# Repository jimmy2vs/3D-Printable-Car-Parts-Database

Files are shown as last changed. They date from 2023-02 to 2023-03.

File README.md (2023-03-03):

# 3D-Printable-Car-Parts-Database

I drive a 1995 BMW M3.  It is an amazing car and brings me so much joy to drive.  It's also slowly disintigrating.  30 year old plastic and glue were not made to last.  

This project started as a way to keep my 90's cars on the road and looking nice.  Tinkering around with this stuff is the thing I can't not do.  Maybe you're the same way.  This is a collection of 3d-printable parts, upholstery patterns, and related repair materials for all sorts of cars from this era.  Take what you find here and apply it to make something for your own car.  Share what you learn with your own enthusiast community.

We've entered an era where we don't fix things anymore.  So many things today aren't repairable or are engineered to have a finite life span.  Cars are no different.  There are so many great sports cars the 80's, 90's and early 2000's.  Icons that are still affordable and loads of fun to drive today.  This project is dedicated to the art and craftsmanship of keeping these cars on the road for many more years to come.

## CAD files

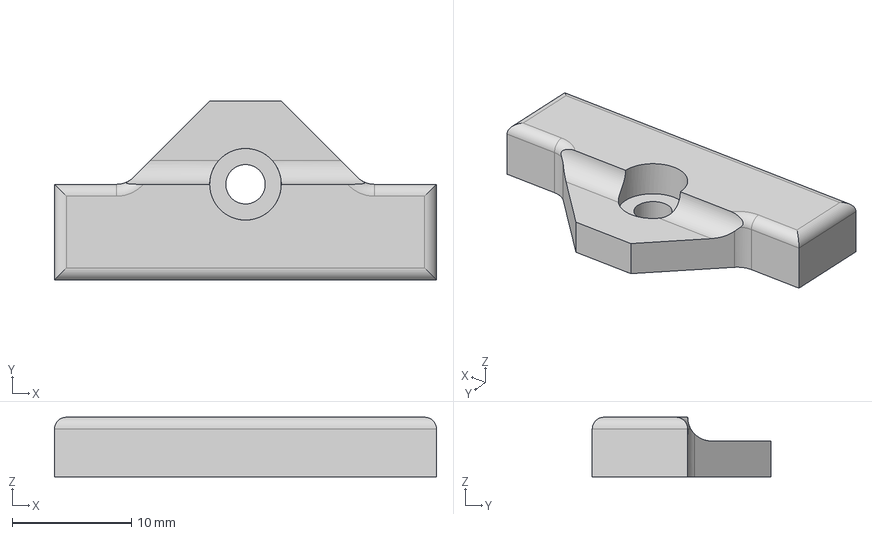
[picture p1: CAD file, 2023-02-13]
BMW/3-series/e36 (1992-1999)/M-tech bumper mesh repair tabs/e36 Front Bumper Mesh Hold Down v2.step
32.0 x 15.0 x 5.00 mm

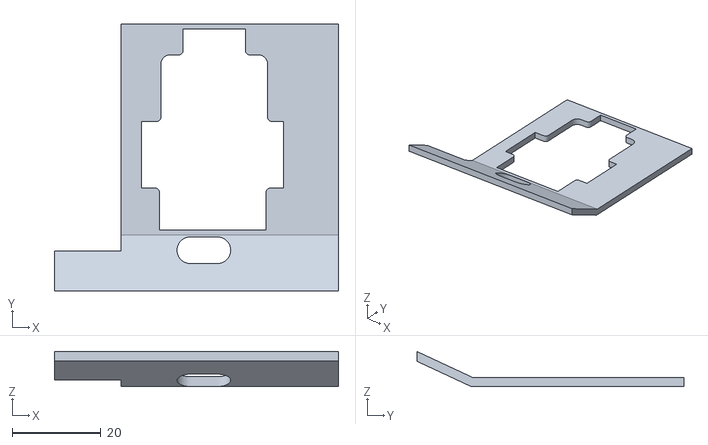
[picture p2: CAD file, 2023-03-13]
Chevrolet/Corvette/C5 (1997-2004)/c5 Knee bolster repair tab RIGHT v11.stl
64.0 x 60.2 x 7.92

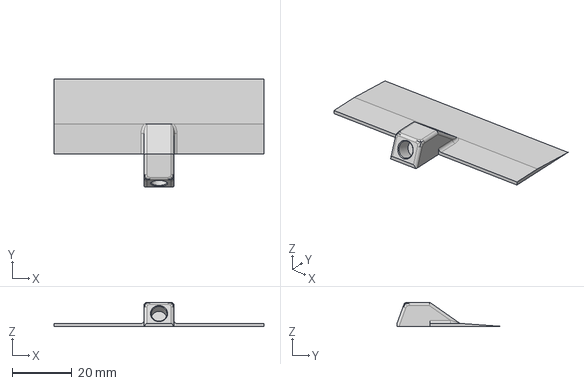
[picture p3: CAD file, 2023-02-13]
BMW/3-series/e36 (1992-1999)/M-tech bumper mesh repair tabs/e36 Front bumper mesh lower mount v10.step
70.0 x 36.0 x 8.08 mm

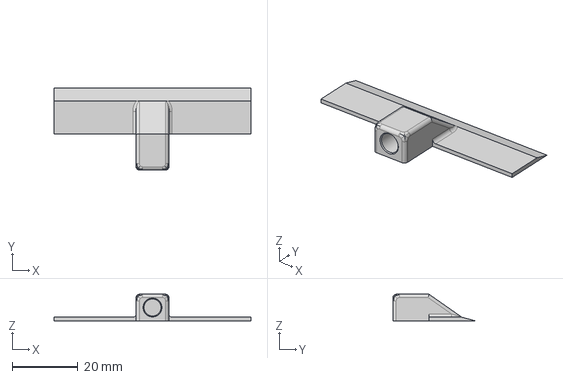
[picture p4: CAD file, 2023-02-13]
BMW/3-series/e36 (1992-1999)/M-tech bumper mesh repair tabs/e36 Front bumper mesh upper mount v10.step
60.0 x 25.0 x 8.08 mm

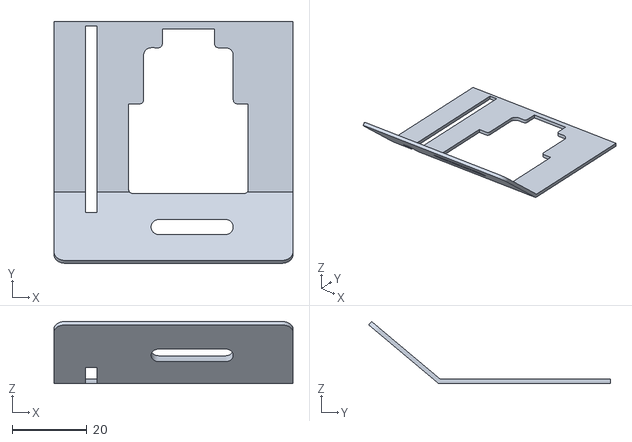
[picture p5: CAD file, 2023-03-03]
Chevrolet/Corvette/C5 (1997-2004)/Knee bolster repair tab v5.stl
64.0 x 64.7 x 16.6

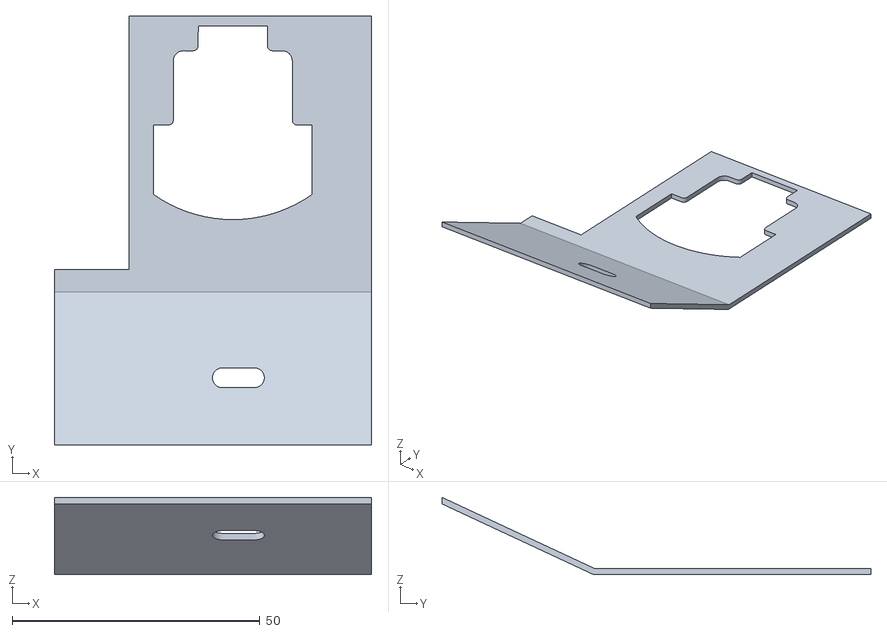
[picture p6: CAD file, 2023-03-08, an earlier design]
Chevrolet/Corvette/C5 (1997-2004)/c5 Knee bolster repair tab RIGHT v6.stl
64.0 x 86.5 x 15.6

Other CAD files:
BMW/3-series/e36 (1992-1999)/M-tech bumper mesh repair tabs/e36 Front Bumper Mesh Hold Down mk2 v2.stl
BMW/3-series/e36 (1992-1999)/M-tech bumper mesh repair tabs/e36 Front bumper mesh lower mount v10.stl
BMW/3-series/e36 (1992-1999)/M-tech bumper mesh repair tabs/e36 Front bumper mesh upper mount v10.stl

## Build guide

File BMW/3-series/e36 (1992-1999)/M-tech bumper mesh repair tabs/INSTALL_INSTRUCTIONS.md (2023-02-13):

# Why make this?
On the 1992-1999 BMW e36 3-series cars with the M-TECH front bumper the lower grill mesh is attached to the bumper cover by a series of plastic posts molded into the grill opening and secured by one-way push clips.  Over time these plastic posts fatigue and break off.  The posts are not individually placeable.  The only remedy is to purchase, paint, and install new bumper cover.  This repair kit replaces the plastic posts and one way-nuts with a bonded in theaded insert and screw-in clamp which is far sturdier and makes the lower grill mesh easily relacable in the event of future damage.

## Print these parts
- e36 Front Bumper Mesh Hold Down (print 5 of these)
- e36 Front bumper mesh lower mount (print 2 of these)
- e36 Front bumper mesh upper mount (print 3 of these)

As for filiament type, PETG or ABS/ASA are preferred.  PLA will work, but may not have long term durability.

## You also need these parts
Available from McMaster-Carr, Amazon, AliExpress, some local hardware stores.
- M3x5mm heat set threaded inserts (5)
- M3x12mm Socket Head Cap Screw (5)
- JB Weld Plastic Bonder (50139) or equivalent #M, Permatex, etc.
- Isopopyl Alcohol

## You should have these tools
- 3mm allen key
- ~40 watt Soldering Iron with the specific tip for an M3 heat set insert
- sharp utility or exacto knife
- A set of rasps or files
- Rotary tool (Dremel, etc) with plastic cutoff wheel
- An assortamant of small to medium size squeeze clamps
- An interior trim pry-tool.

## Installation
1. Remove the front bumper and support it nose down on a table or stand.
2. Remove the existing grill mesh by cutting or prying up any remaining push clips.  An interior trim tool can be used to gently work them free.
3. Clean and inspect the bumper cover for any cracks or other damage around the grill opening.  Stop and repair any problem areas before proceeding.
4. Using the photos below as a guide, scuff the area where the upper and lower mounts will be bonded into place.
5. Clean the cuffed areas with alcohol or another suitable adhesive prep.
6. Spread a modest amount of adhesive on the back side of each mounting tab and set in place.  The threaded hole should be fluch, or just slightly below the lip of the grill opening.
7. Allow at least 24 hours for the adhesive to cure.
8. Place the grill mesh insert into the opening and mark the 5 areas to trim. Trim the grill using the dremel tool.
9. Pleasce the grill mesh back into the opening, it should sit flush against the bumper cover now.
10. Screw in the 5 hold downs to secure the grill mesh to the bumper cover.
11. Reinstall the bumper.

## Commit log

2023-02-13 First project! E36 bumper mesh repair tabs
    [e36 Front Bumper Mesh Hold Down mk2 v2.stl, e36 Front Bumper Mesh Hold Down v2.step, e36 Front bumper mesh lower mount v10.step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]
2023-03-03 First try at repair tab for knee bolster ambient air sensor side
    [Knee bolster repair tab v5.stl]
2023-03-08 Edit some sizing based on photos from first try
    [c5 Knee bolster repair tab RIGHT v6.stl]
2023-03-13 Second try had some major errors, resize again
    [c5 Knee bolster repair tab RIGHT v11.stl]
